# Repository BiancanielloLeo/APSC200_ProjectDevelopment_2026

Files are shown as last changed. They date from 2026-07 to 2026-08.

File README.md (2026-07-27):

##APSC200_ProjectDevelopment_2026

This repository contains the code and documentation for the SWEP 2026 project. Please refer to the documentation for all project details.

The "Software" folder contains all code to be ran on the users computer, the "Firmware" folder contains all the code to be ran on the robots, and the "Hardware" folder contains all the CAD models for the robots.

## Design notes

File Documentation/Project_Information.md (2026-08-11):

APSC 200 Project Development Multi-Agent Differential Drive Robotic System

Project Information

Leo Biancaniello Will Beveridge

Queen’s University Mathematics and Statistics Department

Summer 2026

## Contents

System Overview ................................................................................................................................................ 3 1 Software ..................................................................................................................................................... 4 1.1 Tracker ............................................................................................................................................... 4

1.1.1 ArUco Markers ................................................................................................................................ 4 1.2 Server ................................................................................................................................................. 5 2 Firmware..................................................................................................................................................... 7 2.1 Connection......................................................................................................................................... 7 2.2 Motion Planner.................................................................................................................................... 7 2.3 Motor Control ..................................................................................................................................... 8 2.3.1 Motors ............................................................................................................................................ 8 2.3.2 Encoders ........................................................................................................................................ 8 2.3.3 Pulse Counter ................................................................................................................................. 9 2.3.4 Control Law .................................................................................................................................... 9 2.3.5 Spot Turning Control ..................................................................................................................... 11 2.4 Battery Management ......................................................................................................................... 12 3 Hardware .................................................................................................................................................. 13 3.1 Chassis ............................................................................................................................................ 13 3.1.1 3d Print Settings ............................................................................................................................ 13 3.2 Assembly.......................................................................................................................................... 13 Appendix A: Electronics .................................................................................................................................... 15 A.1 Component Information .......................................................................................................................... 15 A.2 Pin Assignments...................................................................................................................................... 17 A.3 Pin Information ....................................................................................................................................... 18 Appendix B: Testing .......................................................................................................................................... 19 B.1 Feedforward ........................................................................................................................................... 19 B.2 Proportional and Integral ......................................................................................................................... 20 B.3 Turning ................................................................................................................................................... 20 Appendix C: Upgrades ...................................................................................................................................... 20

# System Overview

S

The robots operate on a consistent smooth tile floor

Path following (Free) vs Trajectory Generation (Timed) High and Low level control: Pure Pursuit,

Our goals are Position and Heading, but conventional control is in Linear and Angular Velocity

Collision avoidance should be on the robot itself. If it leaves the frame the server should keep running for the other robots, the one that no longer sees itself in the packets should just stop

# 1 Software

Software constitutes everything ran by the laptop. The system will use a distributed approach where the laptop is responsible for locating the position and heading of each robot, which it then communicates to all the robots that take the information and compute their new headings locally.

“initiation.py” (Should show what the UDP server is sending in the console) (On screen should be (ID, X, Y, Pose) (Simplify start up: List all robot ID’s being used then send 0 when you are done)

“tracker.py”

“udp.py”

Decouple the GUI from the tracking loop so that packets are sent as fast as possible and so that computation for the GUI doesn’t delay the tracker

## 1.1 Tracker

ALogitech C922 Pro Stream Webcam that runs at 30 fps with a 1920x1080p resolution is used to detect theArUco markers on the robots using OpenCV’s computer vision algorithm.

The camera is mounted overhead so there is no lens distortion or optical illusion, thus no anti-warping calibration is needed for the camera. The camera just needs its focus to be set using findFocus.py. The current best focus is a value of 15.

Since an external camera is being used, the camera source in the code needs to be changed from 0 to 1 if the laptop has a webcam*

The camera can view3600x2030mm of the floor so the algorithm should apply a cartesian plane to the center of the screen and convert the robot’s pixel positions to millimetres.

The robot’s positions are averaged from the detection of their four corners and the robot’s headings are taken as the angle between two of their corners in radians and are normalized to [−𝜋, 𝜋] where0° is facing right

DISPLAY FRAME RATE ON CAMERA FEED

## 1.1.1 ArUco Markers

The markers for the robots are a series of pixels that encode a binary number using black and white cells. The marker patterns are unique under rotation so that the pose of the robot can be determined from its marker orientation.

The algorithm detects the markers by looking for the black to white transition on it’s borders so it is important to always have a white border around the markers. The current markers are 95x95mm with a

## 2.5mmwhite border to make them 100x100mmwhich comes out to 375x375 pixels.

When detecting markers, the code returns the position of its four corners and the id of the marker. Then after detection the pose is estimated with the axes being shown (X-axis is Red, the Y-axis is Green, the Z- axis is Blue).

OpenCV has libraries on ArUco markers that provide dictionaries of different marker sizes and number of markers. It is better to use a shorter dictionary that only includes as many markers as you need as the inter-marker distance in the dictionary affects the cameras noise tolerance. We will use the 4x4_50 dictionary.

The markers are printed on matte 100lb cardstock that they do not bend as easily and have less glare

## 1.2 Server

AUDP (User Datagram Protocol) server will be used to broadcast the robots position data from the tracker to the robots. The UDP server will broadcast all robot positions in one packet to the address

## 255.255.255.255 on port 5005 on the router at a rate of 20 Hzto match the20 Hz robot heading logic

BROADCAST_IP = "255.255.255.255"

Since the UDP broadcast goes to every device n the network simultaneously, all robots receive the same packet at the same time.

Packets will be in the form:

- Byte 0 is the Packet Type (uint8) (RUN or STOP)
- Byte 1-4 are Sequence Numbers (uint32)
- Byte 5 is the Number of robots N (uint8)
- Bytes 6+ are the robot records

o 1 byte for Robot ID (uint8) o 2 bytes for X position (int16) - millimeters o 2 bytes for Y position (int16) - millimeters o 2 bytes for Heading (uint16) - radians x 1000 (scaled for int16 transmission)

Big-Endian format should be used so that byte order is unambiguous between the laptop and ESP, and information should be transmitted in millimetresandradians.

The server should have a response if a robot that is said to be active is not seen onscreen. This could be broadcasting a specific position (-9999, -9999) to indicate that the robot was lost or it could have a different response to tell the robot to stop.

WHEN THE ROBOT GOES OUT OF FRAME, THE SERVER JUST REPEATEDLY BROADCASTS IT’S LAST POSITION

There should be a start button. So when the server initializes, it should be in the stopped state, then you manually start it up

Binding SERVER_IP = "" doesn't affect the port. The bind tuple (IP, PORT) has two independent parts: the IP picks which interface on your laptop the socket attaches to, and the port is what your robots actually key on. Your server broadcasts to port 5005, so any robot listening on port 5005 receives the packet — no matter what your laptop's bind IP is. The robots never see your bind IP; they just watch for traffic on the agreed port. So the only thing that must match is the port: server sends to 5005, robots listen on 5005. Use SERVER_IP = "", keep SERVER_PORT = 5005, and you're set.

WHAT IS THE CAMERA LATENCY?

Test packets getting received

# 2 Firmware

Use New API v3.0+, ledcAttach(pin, freq, res) & ledcWrite(pin, duty) & ledcDetach(pin) With 20 kHz frequency and 8-bit resolution

The code that runs on the robots decodes the data from the server, determines the robots next headings, then controls the motors to move the robot. Serial communication should be at a Baud Rate of 115200 BATTERY MONITORING IS JITTERY AND THE VALUES NEED TO BE SMOOTHED

## 2.1 Connection

The robots have a built in WiFi module that will be used to read the port on the server to get the robots positions. Upon startup, the robots onboard LED should be RED when they are not connected to WiFi. Then once they connect to the specified network they should turn BLUE. Then when the robots are able to read the packets from the port they should turn GREEN. The robots should connect to “AgentWifi” with password “12345678” and port 5005 (ALL IT NEEDS IS THE THREE PIECES OF INFO) There should be a watch dog timer on the robots so that if they do not receive a packet for 1000msthey stop to avoid driving off screen.

Always use the newest packet in the sequence and discard old ones

## 2.2 Motion Planner

This should run at 20 Hz. The robot doesn’t need to make changes every loop, but it should compute everything to be able to make a decision The algorithm needs to compute what motor speeds are needed to get the robot to it’s next position using the formulas:

(𝑣 −𝐿⁄ × 𝜔)

2 𝑅𝑃𝑀𝐿 =× 60 2𝜋𝑟 (𝑣 +𝐿⁄ × 𝜔) 2 𝑅𝑃𝑀𝑅 =× 60 2𝜋𝑟

𝑣 is the desired velocity 𝜔 is the desired angular velocity 𝑟 is the radius of the wheel which is 32.5mm 𝐿 is the wheelbase between the two wheels which is 125mm

## 2.3 Motor Control

Two motors will spin at different speeds with the same power due to manufacturing tolerances. For the robots to drive straight and turn accurately, we need to control the motor speeds so that the wheels spin at the desired RPM (60-80 rpm). Thus, we will use feedforwardplusproportionaland integral control. We will run two separate control loops for each motor at 100 Hz.

NEED TO TEST MIN PWM FOR STRAIGHT AND TURNING Without battery voltage reference, the minimum duty to spin seems to be 70-75

## 2.3.1 Motors

The motors used are rated for a 6V input with a speed of 120 rpm at 0.20 kgcm of torque − IN1 and IN2 control direction. Having IN1 HIGH and IN2 LOW means forward, while the reverse means backwards. Both LOW means coast, and both HIGH means brake − STBY enables the motor driver so it must be HIGH to operate − PWM expects a pulse-width modulated square wave where the duty cycle controls the average motor voltage The PWM channel is configured at 20,000 Hz with 8-bit resolution so it runs a frequency of 20,000 Hz where the Duty Cycle can be set from 0 to 255 where 0 is 0% and 255 is 100%

## 2.3.2 Encoders

The encoders are Magnetic Wheel encoders with two hall effect sensors that output in quadrature (A/B channels). The encoders have A and B channels that generate square waves and are shifted so that the leading wave can indicate the direction of the motor spin. Channel A leading channel B means the motor is spinning CCW.

The state of the motor is determined by comparing the current encoder state with the previous encoder state and using a lookup table to determine if there is +1, -1, or 0 ticks.

The formula for the number of ticks per revolution is 7 × 𝐺𝑒𝑎𝑟 𝑅𝑎𝑡𝑖𝑜 × 𝑁𝑢𝑚𝑏𝑒𝑟 𝑜𝑓 𝐸𝑑𝑔𝑒𝑠. So, counting only the rising edge of one channel will give 350 ticks, while counting the change gives 700 ticks, and counting the change on both channels gives 1400 ticks which we will use.

## 2.3.3 Pulse Counter

Every time the encoders signal has a rising or falling edge, the CPU needs to take an interrupt to decode the signal. The ESP’s hardware PCNT (Pulse Counter) peripheral can count encoder pulses directly I hardware, so all the CPU needs to do is read the counter register when it’s needed.

The ESP32-S3-DEVKITC-1 has 4 hardware PCNT units (PCNT_UNIT_0 to PCNT_UNIT_3). Unit 0 will be used for the Left motor and Unit 1 will be used for the Right motor. In each unit are two other channels which will be used to read the two channels of each encoder.

Channel 0 is for Encoder Channel A and Channel 1 is for Encoder Channel B with their logic flipped in order to follow proper sequencing such that 00 -> 01 -> 11 -> 10… is Forward and 00 -> 10 -> 11 -> 01 is Backwards.

The ticks are stored in a 16-bit integer that wraps at ±32767. The program needs to use the current and last reading of ticks as that difference will be how much the wheel spun between intervals. The 16-bit integer arithmetic wraps will be automatically handled by the delta math. Just make sure that currentTicks and deltaTicks are both int16_t so that they wrap around the same.

In the function there is an invertDirection clause to make it so that the readings are dependent on if the robot is moving forwards or backwards, so the left unit is inverted and the right unit is normal.

The PCNT can accumulate ticks before the first loop which will through off the delta. Initially reset the accumulation or do something to prevent this issue.

## 2.3.4 Control Law

In this system, we view the input as the desired RPM from the motor, the control input being the PWM duty that we send, and the output being the actual speed of the motor which we read from the encoder.

Since we know somewhat about the dynamics of the motors, we will measure the PWM duty required to reach different RPM of the motor and then use those values for Feed forward control and then additionally use Proportionaland Integral control to get to our desired output.

The manage the Integral control, there is an anti-wind up clause and clamping so that the PWM duty never exceeds the safe rating of ~70%

NEEDS TO HANDLE SPINNING IN EITHER DIRECTION

The feedforward model duty = Kv·RPM + Ks is only valid for forward motion. The Ks term represents the static friction offset — the extra duty needed to overcome stiction and start moving. Because friction always opposes motion, this offset must always push in the direction of travel. For a negative (reverse) RPM command, the sign of the Ks term must follow the command direction:

- Forward (RPM > 0): duty = Kv·RPM + Ks
- Reverse (RPM < 0): duty = Kv·RPM − Ks

Generalized: duty = Kv·RPM + sign(RPM)·Ks If Ks is left positive for a reverse command, the offset partially cancels the command near zero RPM, making the motor sluggish to break free or unresponsive at low reverse speeds. Note that "inverting Ks" means flipping the sign of the term to match direction — Ks itself remains a positive constant. Companion changes required for reverse to work:

## 1. Signed feedforward output — compute the duty magnitude from |RPM|, then apply the

command's sign to the result.

## 2. Direction-aware motor drive — the motor function must set the H-bridge direction pins

from the sign of the duty, and write the magnitude to the PWM.

## 3. Symmetric saturation — the PI output and saturation limits must span [−MAX_DUTY,

+MAX_DUTY] instead of [0, MAX_DUTY], checking both rails.

## 4. Encoder measurement — already handles sign correctly (PCNT counts down for reverse),

so no change needed; the error term works in both directions. Accuracy note: Forward and reverse Ks are often not equal, due to direction-dependent gearbox and brush friction. For best accuracy, characterize each direction separately to obtain Ks_forward and Ks_reverse. Asymmetric Ks is the likely cause if the robot tracks straight forward but veers in reverse.

Thus the control law is

𝑃𝑊𝑀 𝑑𝑢𝑡𝑦 = (𝐾𝑣 × 𝑅𝑃𝑀𝑑𝑒𝑠𝑖𝑟𝑒𝑑 + 𝐾𝑠 × 𝑠𝑖𝑔𝑛(𝑅𝑃𝑀)) + (𝐾𝑃 × 𝐸𝑟𝑟𝑜𝑟 + 𝐾𝐼 × ∫ 𝐸𝑟𝑟𝑜𝑟)

Where Kv is the duty per RPM and Ks is the minimum PWM needed to overcome static friction which are determined through testing. It seems that 𝐾𝑣 should be around 1 and 𝐾𝑠 should be around 46.

A good starting point for 𝐾𝑃 is 2.5, and for 𝐾𝐼 is 1

Acceleration

Startup Acceleration Logic (Slew-Rate Limiting)

Problem. The largest source of heading error is the initial startup. When both motors are commanded from zero to a target RPM instantaneously, they do not break free at the same moment — small differences in static friction (Ks) and gearbox drag mean one wheel starts turning a few milliseconds before the other. During that brief window the robot pivots slightly. Because heading error is the integral of the speed difference between the wheels, any error that occurs before the PI loop catches up is permanent — the loop matches wheelspeeds thereafter but never undoes the initial pivot. Solution. Rather than commanding the target RPM instantly, ramp it up gradually from zero using a slew-rate limit.

This keeps both motors in the low-speed region longer, where the PI loop is actively correcting, so the instantaneous speed difference stays small throughout startup. A small difference over a gentle ramp produces far less heading error than a large difference over a sharp transient. It also reduces wheel slip and current spikes. Implementation. The control law itself is unchanged. A "current target" is maintained that chases the "commanded target" at a bounded rate each control tick: maxDelta = MAX_ACCEL_RPM_PER_SEC × dt rampedTarget moves toward commandedTarget by at most maxDelta per tick The ramped target (not the raw command) is then fed into the feedforward and error calculations. Key requirements:

- Shared ramp profile. Both wheels must ramp from a common profile and reach their targets

simultaneously. For straight driving, both use the same rate and target. For arcing (unequal wheel speeds), the wheels must ramp proportionally — scaling each wheel's rate so the ratio between them stays constant and both arrive together — otherwise the faster-arriving wheel briefly curves the path.

- Rate tuning. Start around 300–500 RPM/s and tune on the floor using the Serial Plotter. The two

actual-RPM traces should rise together and overlap during the ramp. Choose the fastest rate that still gives clean, matched startup; slower reduces heading error but launches sluggishly. Assessment. Worth implementing where heading accuracy matters, since it directly targets the identified startup failure mode. It is a small, low-risk addition — a few lines feeding a ramped target into the existing loop, with no change to characterization or the control law — at the cost of a slightly slower launch, which is an acceptable trade for straight-line heading.

## 2.3.5 Spot Turning Control

To turn on the spot, find the lowest DUTY that the robot needs to spin and then make a proportional plus minimum controller where the robot spins and get’s it’s heading from the server until it is at the desired angle.

The robot should try to turn in an open loop fashion where it only relies on the encoder ticks and then when it thinks it is in the right spot, it reads the next packet to check it’s position and adjust

BRAKE instead of COAST when at desired angle

arc_per_wheel = (|degrees| / 360) × π × wheel_track

ticks = arc_per_wheel / wheel_circumference × ticks_per_rev

Cap Spinning at 120 DUTY NEED MINIMUM TURNING DUTY + WHEELBASE CALIBRATION

## 2.4 Battery Management

𝑉𝑚𝑜𝑡𝑜𝑟 = 𝐷𝑢𝑡𝑦 × 𝑉𝑏𝑎𝑡𝑡𝑒𝑟𝑦

𝑃𝑊𝑀 𝑐𝑜𝑚𝑚𝑎𝑛𝑑 𝐷𝑢𝑡𝑦 =

255 Cap Vmotor at 6V so we aren’t running too much voltage to the motors The PWM duty cycle is between 0 and 1, but registered from 0-255

𝑉𝑛𝑜𝑚𝑖𝑛𝑎𝑙 𝑃𝑊𝑀𝑜𝑢𝑡 = 𝑃𝑊𝑀𝑐𝑜𝑚𝑚𝑎𝑛𝑑 × 𝑉𝑏𝑎𝑡𝑡𝑒𝑟𝑦 Example

## 7.2

𝑃𝑊𝑀𝑜𝑢𝑡 = 128 ×= 109.7

## 8.4

The battery readings are smoothed out with filtering. Moving average ring buffer with 16 samples only. It should update the battery voltage value at a frequency of 5 Hz

Voltage Divider 100 Kohm and 47 Kohm Batteries 7.2V nominal, 8.4V fully charged, 6.0V is the lowest it can safely drop Check everything with a multimeter

# 3 Hardware

The components will be assembled on two breadboards with a power rail in-between and be housed in a 3d printed chassis.

## 3.1 Chassis

The robot’s chassis are 100x100x90mm with2.5mm thick walls so that the interior is 95x95x90mm. The wheels are placed on the centerline of the chassis so that it can turn in place, and skid pads are added to the front and back to aid in balancing.

## 3.1.1 3d Print Settings

## 1.75mm PETG will be used with a 15% infill and 0.2mm layer height

## 3.2 Assembly

The assembly of the robots is very important and it should be done properly so that there are not any hardware issues in the future. First you must solder extensions onto the battery pack so that the Ground and Power wires are both 20cm. Then you must solder the Power wire to the switch and make the output wire 10cm. Then you need to extend all of the motor wires with Male DuPont cables so that they can be stuck into the breadboard. Motor wires should be cut at 9cmand have1. 5cm stripped for splicing. Then some 22 AWGwire should be cut to 12cmand have0. 5cm stripped for splicing. They should be connected with a V-Shape Twist Splice.

When assembling the breadboard circuits,22 AWG wires should be used and there should be 5mm of exposed wire on each end to snuggly fit into the holes. DON’T PUSH ON THE BACK OF THE ENCODER WHEN PUTTING IN MOTORS, IT WILL BEND THE MOTOR SHAFT AND BREAK THE MOTOR

The motors are press fit with their wires going towards the front of the chassis and being routed up through the cable holes. The Battery Pack goes in wire side first and has it’s wires pulled into the cable holder on the left side of the chassis. The switch should have the smooth side down and be secured with a zip tie.

Figure 1: Electronics Schematic

# Appendix A: Electronics

The robot uses an ESP32-S3-DEVKITC-1 v1.1 microcontroller that runs at 3.3V logic and has built-in WiFi. The motors have built in encoders and are controlled by a TB6612FNG motor driver. The robot will be powered by six AA batteries with a nominal voltage of 7.2V, going as high as 8.4V when fully charged.

The microcontroller uses Micro-USB and has a USB Port and a USB-to-UART Port. The USB-to-UART port is used for programming and serial monitoring. When programming, the ESP has automatic bootloader entry so the BOOT and RESET buttons do not need to be pressed, but they should be made accessible for troubleshooting.

The motor driver can accept 4.5V to 13.5V, but the motors are only rated for 6V, so the motor driver must be instructed to limit the PWM output to less than 70% to prevent the 7.2V of the battery from damaging the motors.

A voltage divider circuit is connected from the battery to an analog pin on the microcontroller so that the battery voltage can be monitored.

There is a capacitor at the battery terminals and at the microcontrollers terminals to smooth out current flow when components spontaneously demand high currents.

## A.1 Component Information

Microcontroller Development Board: − $23. 10 CAD -ESP32-S3-DEVKITC-1-N8R8 v1. 1, Adafruit 5336, Datasheet − 32-bit Dual Core Xtensa LX7 240MHz, 8MB PSRAM, 8MB Flash, Wi-Fi 4 − Can be programmed with exposed BOOT and RESET buttons − 45 GPIOs (0-21 and 26-48), 4x SPI, 3x UART, 2x I2C, all PWM capable except Powers, Grounds, and Resets − Has an onboard RGB LED − Has peak Wi-Fi draws of ~350mA Motor Driver: − $10. 04 CAD -TB6612FNG DC Motor Driver, Adafruit 2448, Datasheet − 2. 7V – 5V Logic and 4. 5V – 13. 5V Motor Supply − 1. 2A current per channel with 3.

2A peak − Supports PWM speed control, braking, and direction control − Internal Flyback, Thermal Shutdown, and Reverse Polarity Protections − ~90% Efficiency Motor with built in Encoder: − $18. 06 CAD -N20 DC Motor with Magnetic Encoder 1:50, Adafruit 4638, Datasheet − 6V DC 0. 2W with 100 mA running current and a ~200mA stall current (Can accept 4. 5V)

− 200 RPM No Load speed and 120 RPM Rated speed − 0. 20 Kgcm Rated torque and 0. 32 Kgcm Stall torque − 3-5V VCC for the Magnetic Quadrature Encoder with Dual Hall-Effect Sensors − Encoder output voltage is equal to the encoder supply voltage − PWM must be limited at 70% to semi-match battery voltage to input voltage* Wheels: − $3. 00 CAD -65mm Wheel for N20 Motor, Adafruit 4205, Datasheet − Hub is specifically designed to match the N20 D-Shaft Voltage Regulator: − $10. 84 CAD -AP63203 3. 3V Buck Regulator, SparkFun COM-18356, Datasheet − 3.

8V – 32V Input − 2A Max continuous output − ~88% Efficiency − Overcurrent, Thermal Shutdown, Undervoltage, Short-Circuit, and Electromagnetic Interference Protection − Recommends additional external capacitors* Battery: − $21. 99 CAD -Performance AA Rechargeable Batteries (This is a pack of 12, we need 6)

− Rechargeable Ni-MH 1. 2V 2400mAh − 7. 2V Nominal and 8. 4V when fully charged − $4. 20 CAD -Battery Holder, Datasheet Voltage Divider: − R1 = 100KΩ + R2 = 47KΩ − Current drain of 61𝜇A − Pin voltage never exceeds 3. 3V Capacitors: − 100𝜇F Electrolytic Capacitor − Between battery positive and ground before the converter − Must be rated above max battery voltage (8. 4V) − Positive Leg on positive battery and Negative Leg on ground − 47𝜇F Ceramic Capacitor − Close to ESP power pins − One leg on 3. 3v ESP pin and other leg on GND ESP pin Rocker Switch: − $1.

08 CAD -Two Prong Rocker Switch, SparkFun COM-11138, Datasheet − Backup $4. 40 CAD -Two Pring Rocker Switch, Datasheet − Two modes: ON and OFF − Two pins (One for IN, one for OUT)

2x 400-Pin Breadboards: − $3.27 CAD -400 Pin Breadboard − Needs removable rails 4x 2 Colour LEDS − $_.__ CAD –

− 5mm Diameter

## A.2 Pin Assignments

Battery: − Positive terminal goes to VIN on the Voltage Regulator − Positive terminal goes to PWRIN on the Motor Driver − Negative terminal goes to GND on the Voltage Regulator Voltage Regulator: − GND is tied to GND on the ESP − 3. 3V is tied to 3. 3V on the ESP Left Motor with Encoder: − M1 (White) is tied to MOTORA2 on the Motor Driver (So AIN1 HIGH, AIN2 LOW is Forward) − M2 (Red) is tied to MOTORA1 on the Motor Driver − VCC (Black) is tied to 3.

3V on the ESP − GND (Blue) is tied to GND on the ESP − C1 (Green) is tied to GPIO1 on the ESP(Direction is handled in code) − C2 (Yellow) is tied to GPIO2 on the ESP Right Motor with Encoder: − M1 (White) is tied to MOTORB1 on the Motor Driver (So BIN1 High, BIN2 LOW is Forward) − M2 (Red) is tied to MOTORB2 on the Motor Driver − VCC (Black) is tied to 3.

3V on the ESP − GND (Blue) is tied to GND on the ESP − C1 (Green) is tied to GPIO21 on the ESP (Direction is handled in code) − C2 (Yellow) is tied to GPIO47 on the ESP Motor Driver: − VCC is tied to 3. 3V on the ESP − GND is tied to GND on the ESP − PWMA is tied to GPIO4 on the ESP − AIN2 is tied to GPIO5 on the ESP − AIN1 is tied to GPIO6 on the ESP − STBY is tied to GPIO7 on the ESP − BIN1 is tied to GPIO8 on the ESP

− BIN2 is tied to GPIO9 on the ESP − PWMB is tied to GPIO10 on the ESP

Voltage Divider: − Positive Terminal of the battery goes to a 100KΩ resistor then is tied to GPIO18 on the ESP − The line to GPIO18 has a junction that goes to a 47KΩ that is tied to the negative terminal of the battery

Capacitors: − 100𝜇F Electrolytic Capacitor: Long (Positive) leg on the positive wire and Short (Negative) leg on the negative wire from the battery pack − 47𝜇F Ceramic Capacitor: Put as close as possible to the 3.3V and GND pins on the ESP

## A.3 Pin Information

- Total Pins:

o GPIO0-21 and GPIO26-48

- Safe Pins:

o GPIO1-2, GPIO4-18, GPIO21, GPIO39-42, GPIO47, GPIO48

- Unsafe Pins:

o GPIO0, GPIO3, GPIO45, GPIO46 are Boot Strapping Pins o GPIO19-20 are USB-JTAG Pins o GPIO26-32 are Internal SPI Flash / PSRAM Pins o GPIO33-37 are Octal SPI Expansion Pins o GPIO38 is the Onboard RGB LED o GPIO43-44 are TX and RX Pins

Pins 11, 12, 13, 14 are good spots for LED’s

# Appendix B: Testing

S

## B.1 Feedforward

Characterization

Purpose. Determine the feedforward model duty = Kv·RPM + Ks for each motor, where Kv is the duty required per unit RPM and Ks is the static offset (the duty needed to overcome friction and begin moving). This model provides the baseline duty command; the PI loop corrects residual error. Method. Characterization is performed with the wheels off the ground (no load). No-load conditions give the lowest measurement variance and ensure both motors are measured under identical conditions, which matters because the goal is matching the two motors rather than hitting an absolute RPM. The load-dependent behavior on the floor is handled by the PI loop, not the feedforward.

The routine steps the PWM duty from a minimum to a maximum value, recording steady-state RPM at each step, then fits a line by least-squares regression to extract Kv and Ks. Measures taken to improve accuracy and consistency:

- Raised the duty floor (MIN_MOVE_DUTY = 55) to avoid the low-duty stiction region, where

erratic RPM readings distort the fitted offset.

- Breakaway rejection — data points below 5 RPM (motor failed to break free) are excluded from

the fit.

- Long, true-timed measurement windows — 1000 ms per point, timed with micros() rather

than assuming the delay duration, to minimize quantization noise.

- Averaging— 5 sub-samples averaged per duty point.
- Bidirectional sweep — duty is swept up and then down, and both directions are combined in

the fit, averaging out backlash and friction hysteresis.

- Finer duty steps (CHAR_DUTY_STEP = 10) for more data points and a more stable fit.
- Warm-up — motors are run before characterizing so cold-vs-warm gearbox drag does not bias

results.

- Fit quality (R²) is computed and reported for each motor, providing a direct measure of how well

the linear model fits and flagging noisy data. Results. After these changes, characterization became consistent and repeatable across runs. Representative fits: both motors converged to Kv ≈ 0.97 and Ks ≈ 31, with R² ≥ 0.997 on every fit. Run- to-run variation in Kv fell to roughly 1.5%, small enough that the PI loop absorbs the difference. This was a marked improvement over early runs, where Ks varied by as much as 10 duty counts between runs and the two motors disagreed by ~8%.

No Load Characterization

No Load PI

Loaded PI

Safe range is 30-120 RPM

## B.2 Proportional and Integral

s

## B.3 Turning

The value for the wheelbase is what will determine the turning dynamics

# Appendix C: Upgrades

S

- Possibly use separate batteries for motors and for logic to prevent sag
- Switch to Lithium Polymer batteries and include a charging circuit on the robot
- Use buck-boost converters for both the Microcontroller and Motor Driver, but add drain protection
- Could switch to better motors that have higher torque at the same speed, but may not be necessary
- Could switch to motors that don’t have exposed gears

•

- Implement UWB positioning
- Make the PWM Duty for motor control dependent on the battery level

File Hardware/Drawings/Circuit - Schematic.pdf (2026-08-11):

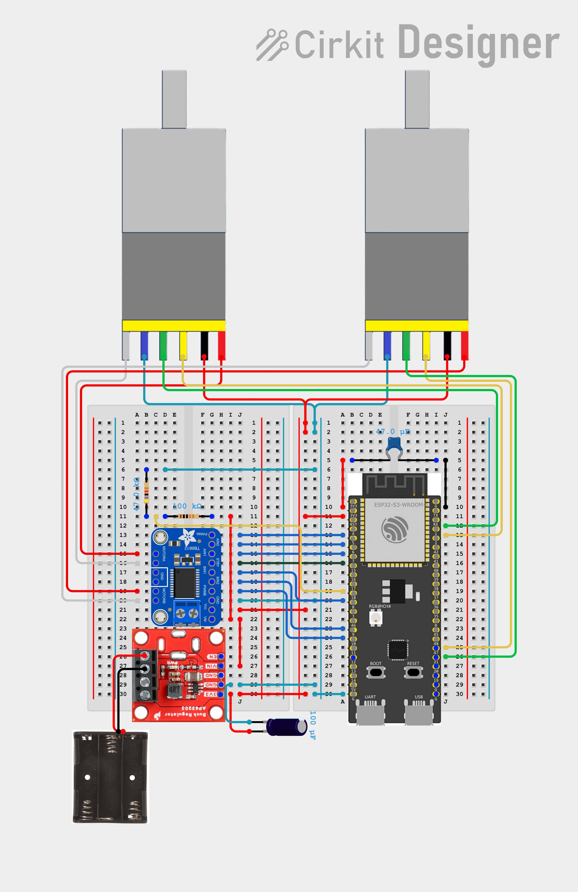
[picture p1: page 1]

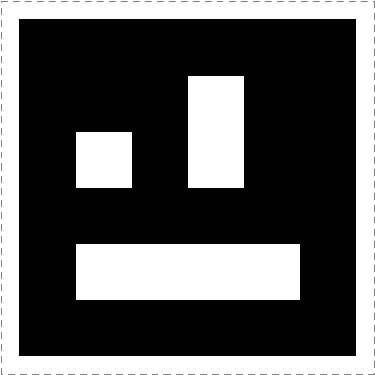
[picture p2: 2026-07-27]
Software/Computer Vision/4x4_50 ArUcos/aruco13.png

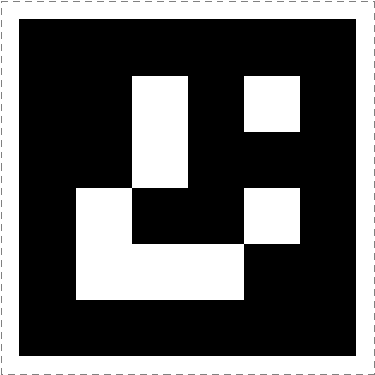
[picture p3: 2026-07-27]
Software/Computer Vision/4x4_50 ArUcos/aruco4.png

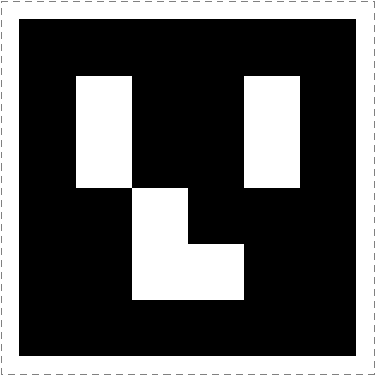
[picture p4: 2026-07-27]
Software/Computer Vision/4x4_50 ArUcos/aruco3.png

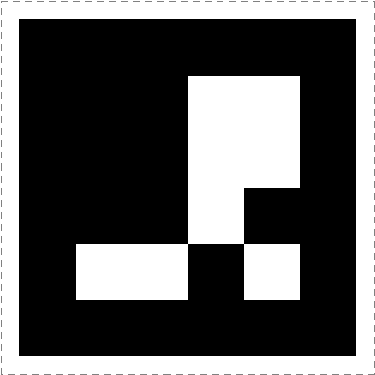
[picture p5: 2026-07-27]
Software/Computer Vision/4x4_50 ArUcos/aruco2.png

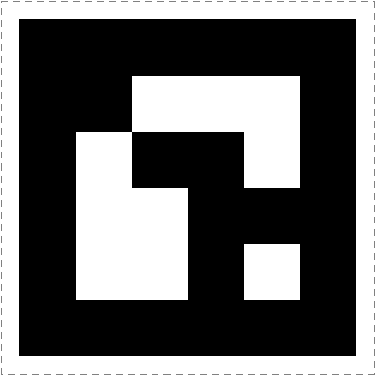
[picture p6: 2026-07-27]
Software/Computer Vision/4x4_50 ArUcos/aruco5.png

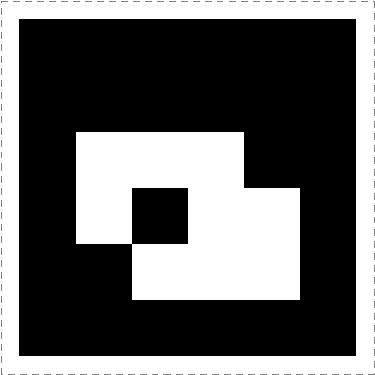
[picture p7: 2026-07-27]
Software/Computer Vision/4x4_50 ArUcos/aruco12.png

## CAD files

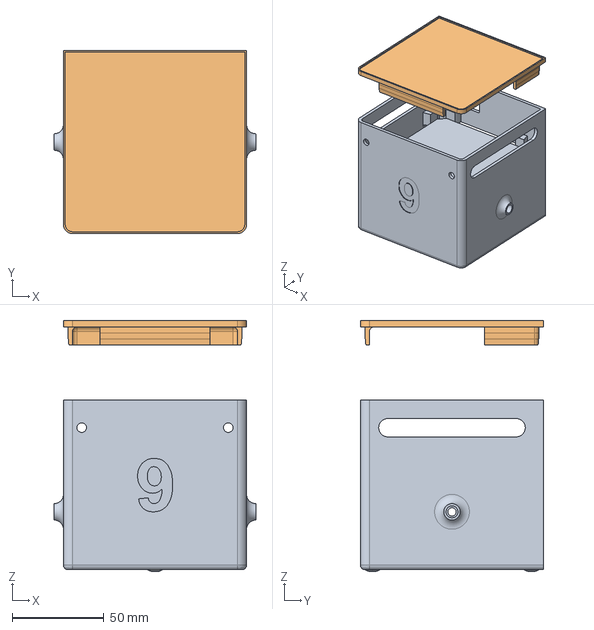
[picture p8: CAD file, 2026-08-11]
Hardware/Step Files/Chassis - 9.step
110.0 x 100.0 x 137.0 mm

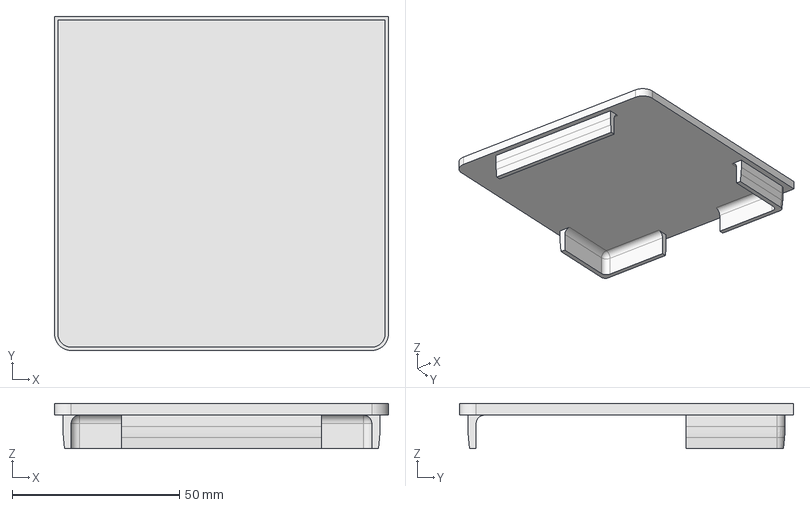
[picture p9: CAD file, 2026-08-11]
Hardware/Step Files/Roof - Blank.step
100.0 x 100.0 x 13.5 mm

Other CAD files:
Hardware/Step Files/Chassis - 8.step
Hardware/Step Files/Chassis - 7.step
Hardware/Step Files/Chassis - 2.step
Hardware/Step Files/Chassis - 1.step
Hardware/Step Files/Chassis - 4.step
Hardware/Step Files/Chassis - 6.step
Hardware/Step Files/Chassis - 11.step
Hardware/Step Files/Chassis - 3.step
Hardware/Step Files/Chassis - 12.step
Hardware/Step Files/Chassis - 5.step
Hardware/Step Files/Chassis - 10.step
Hardware/Step Files/Chassis - Blank.step
Hardware/Chassis - Blank.f3d

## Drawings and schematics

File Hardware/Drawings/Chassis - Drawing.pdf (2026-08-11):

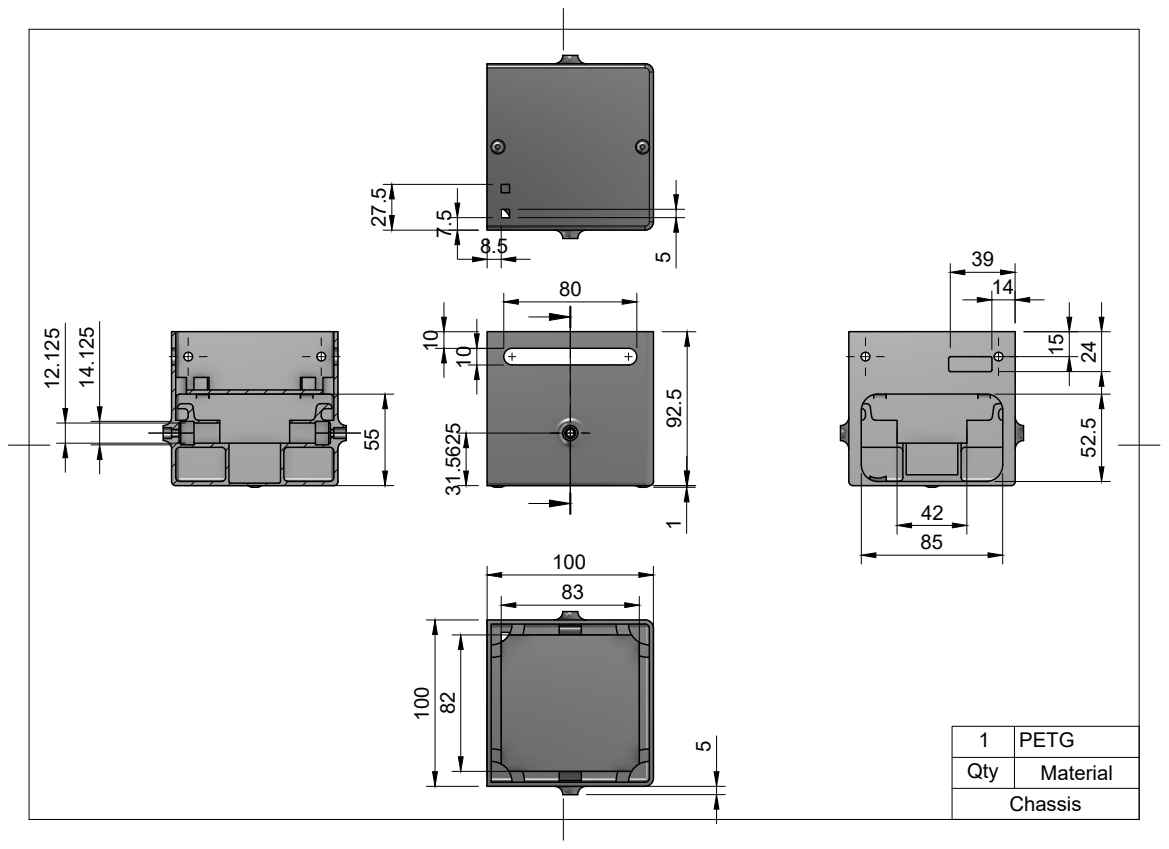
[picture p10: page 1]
Qty; Material 1; PETG 92.5 100

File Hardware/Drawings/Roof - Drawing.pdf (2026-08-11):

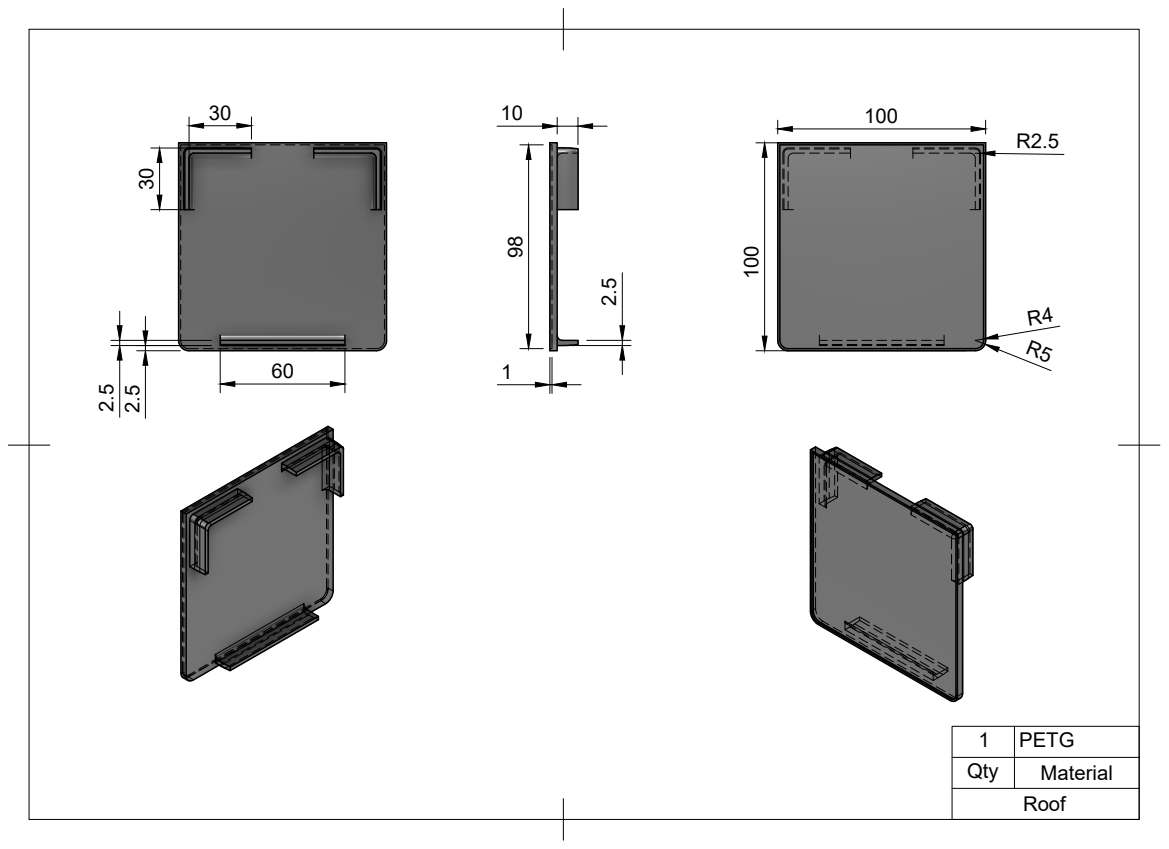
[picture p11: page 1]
Qty; Material 1; PETG

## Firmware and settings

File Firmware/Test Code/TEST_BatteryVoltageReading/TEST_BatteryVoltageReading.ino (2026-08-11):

// =============================================================================
// Simple Battery Monitor + Variable Motor Speed
// =============================================================================

#define BATTERY_PIN 18
#define PWMA_PIN    4
#define PWMB_PIN    10
#define AIN1_PIN    6
#define AIN2_PIN    5
#define BIN1_PIN    8
#define BIN2_PIN    9
#define STBY_PIN    7

// --- Voltage Divider ---
#define R1          100000.0f
#define R2           47000.0f
#define DIVIDER_RATIO (R2 / (R1 + R2))  // 0.3197
#define ADC_RESOLUTION 4095.0f
#define ADC_VREF    3.3f

// --- Moving Average Filter ---
#define MA_WINDOW 16
static float maBuffer[MA_WINDOW];
static int maIndex = 0;
static bool maFilled = false;

// --- PWM ---
#define PWM_FREQ 20000
#define PWM_RESOLUTION 8

// --- Runtime state ---
static int g_motorDuty = 0;
static bool g_motorsRunning = false;
static unsigned long g_startTime = 0;
static float g_startVoltage = 0.0f;

float batteryReadVoltage() {
    long sum = 0;
    for (int i = 0; i < 8; i++) {
        sum += analogRead(BATTERY_PIN);
    }
    float adcAvg = sum / 8.0f;
    float pinVolts = (adcAvg / ADC_RESOLUTION) * ADC_VREF;
    float battVolts = pinVolts / DIVIDER_RATIO;
    return battVolts;
}

float batteryGetFiltered() {
    float raw = batteryReadVoltage();
    
    // Add to moving average buffer
    maBuffer[maIndex] = raw;
    maIndex = (maIndex + 1) % MA_WINDOW;
    
    // Average the buffer
    float sum = 0;
    for (int i = 0; i < MA_WINDOW; i++) {
        sum += maBuffer[i];
    }
    return sum / MA_WINDOW;
}

// Scale duty based on battery voltage
// At 7.2V nominal: duty = requested
// At lower voltage: duty scales up to maintain torque
// At higher voltage: duty scales down to protect motor
int scaleDutyByBattery(int requestedDuty, float batteryVoltage) {
    float scaleFactor = 7.2f / batteryVoltage;  // Normalize to 7.2V
    int scaledDuty = (int)(requestedDuty * scaleFactor);
    
    // Cap at 255 to avoid overflow
    if (scaledDuty > 255) scaledDuty = 255;
    
    return scaledDuty;
}

void motorSetDuty(int dutyA, int dutyB, float batteryVoltage) {
    int scaledA = scaleDutyByBattery(dutyA, batteryVoltage);
    int scaledB = scaleDutyByBattery(dutyB, batteryVoltage);
    
    digitalWrite(STBY_PIN, HIGH);
    digitalWrite(AIN1_PIN, HIGH);
    digitalWrite(AIN2_PIN, LOW);
    digitalWrite(BIN1_PIN, HIGH);
    digitalWrite(BIN2_PIN, LOW);
    ledcWrite(PWMA_PIN, scaledA);
    ledcWrite(PWMB_PIN, scaledB);
}

void motorStop() {
    ledcWrite(PWMA_PIN, 0);
    ledcWrite(PWMB_PIN, 0);
    digitalWrite(STBY_PIN, LOW);
    g_motorsRunning = false;
}

void printMenu() {
    Serial.println("\n=== Battery Monitor + Motor Control ===");
    Serial.println("Commands:");
    Serial.println("  run <0-255> - Run motors at duty (watch battery drain)");
    Serial.println("  stop - Stop motors");
    Serial.println("  a <0-255> - Set motor A speed (one-time)");
    Serial.println("  b <0-255> - Set motor B speed (one-time)");
    Serial.println("  ab <0-255> - Set both motors (one-time)");
    Serial.println("  m - Show this menu");
    Serial.println("====================================\n");
}

void setup() {
    Serial.begin(115200);
    delay(1000);
    
    pinMode(BATTERY_PIN, INPUT);
    pinMode(AIN1_PIN, OUTPUT);
    pinMode(AIN2_PIN, OUTPUT);
    pinMode(BIN1_PIN, OUTPUT);
    pinMode(BIN2_PIN, OUTPUT);
    pinMode(STBY_PIN, OUTPUT);
    
    ledcAttach(PWMA_PIN, PWM_FREQ, PWM_RESOLUTION);
    ledcAttach(PWMB_PIN, PWM_FREQ, PWM_RESOLUTION);
    
    // Seed moving average
    for (int i = 0; i < MA_WINDOW; i++) {
        maBuffer[i] = batteryReadVoltage();
    }
    
    printMenu();
}

void loop() {
    float v = batteryGetFiltered();
    
    // Print battery every 1000ms
    static unsigned long lastPrint = 0;
    if (millis() - lastPrint >= 1000) {
        lastPrint = millis();
        float pct = (v - 6.0) / (8.4 - 6.0) * 100.0f;
        if (pct > 100) pct = 100;
        if (pct < 0) pct = 0;
        Serial.printf("Battery: %.2fV  (%.1f%%)\n", v, pct);
    }
    
    // Keep motors running if in continuous mode
    if (g_motorsRunning) {
        motorSetDuty(g_motorDuty, g_motorDuty, v);
    }
    
    // Parse serial commands
    if (Serial.available()) {
        String input = Serial.readStringUntil('\n');
        input.trim();
        
        // Split command and argument
        int spaceIndex = input.indexOf(' ');
        String cmd = (spaceIndex > 0) ? input.substring(0, spaceIndex) : input;
        
        if (cmd == "run") {
            int duty = input.substring(spaceIndex + 1).toInt();
            g_motorDuty = duty;
            g_motorsRunning = true;
            g_startTime = millis();
            g_startVoltage = v;
            int scaled = scaleDutyByBattery(duty, v);
            Serial.printf("Running motors at %d (scaled to %d)\n", duty, scaled);
        }
        else if (cmd == "stop") {
            motorStop();
            Serial.println("Motors stopped");
        }
        else if (cmd == "a") {
            int duty = input.substring(spaceIndex + 1).toInt();
            motorSetDuty(duty, 0, v);
            int scaled = scaleDutyByBattery(duty, v);
            Serial.printf("Motor A: %d (scaled to %d)\n", duty, scaled);
        }
        else if (cmd == "b") {
            int duty = input.substring(spaceIndex + 1).toInt();
            motorSetDuty(0, duty, v);
            int scaled = scaleDutyByBattery(duty, v);
            Serial.printf("Motor B: %d (scaled to %d)\n", duty, scaled);
        }
        else if (cmd == "ab") {
            int duty = input.substring(spaceIndex + 1).toInt();
            motorSetDuty(duty, duty, v);
            int scaled = scaleDutyByBattery(duty, v);
            Serial.printf("Both motors: %d (scaled to %d)\n", duty, scaled);
        }
        else if (cmd == "m") {
            printMenu();
        }
    }
}

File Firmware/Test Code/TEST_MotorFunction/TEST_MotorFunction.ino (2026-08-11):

//Leo Biancaniello + Claude

// ============================================================
// This code is intended to test the motors response to different inputs
// When the robot is assembled, run this test first to check the motors
//
// Connect the usb to your device and use the serial monitor to pick between different tests
// Watch the motors and check that the response is as expected
// ============================================================


// --- Pin Definitions ---
#define PWMA_PIN   4
#define AIN1_PIN   6
#define AIN2_PIN   5
#define STBY_PIN   7
#define BIN1_PIN   8
#define BIN2_PIN   9
#define PWMB_PIN   10

// --- PWM Config ---
#define PWM_FREQ       20000   // 20 kHz
#define PWM_RESOLUTION 8       // 8-bit (0–255)
#define MAX_DUTY       178     // 70% of 255 — motor voltage cap
#define TEST_DUTY      128     // 50% — used for on/coast/brake tests
#define RAMP_STEP_MS   15      // ms between ramp steps

// ============================================================
//  Setup
// ============================================================
void setup() {
  Serial.begin(115200);
  while (!Serial) delay(10);

  pinMode(AIN1_PIN, OUTPUT);
  pinMode(AIN2_PIN, OUTPUT);
  pinMode(BIN1_PIN, OUTPUT);
  pinMode(BIN2_PIN, OUTPUT);
  pinMode(STBY_PIN, OUTPUT);

  // LEDC pin-based API (ESP32 Arduino Core v3.0+)
  ledcAttach(PWMA_PIN, PWM_FREQ, PWM_RESOLUTION);
  ledcAttach(PWMB_PIN, PWM_FREQ, PWM_RESOLUTION);

  // Start safe
  allOff();

  printMenu();
}

// ============================================================
//  Main Loop — Serial Menu
// ============================================================
void loop() {
  if (Serial.available()) {
    char cmd = Serial.read();
    while (Serial.available()) Serial.read(); // flush newline

    switch (cmd) {
      case '1': testOnLeft();   break;
      case '2': testOnRight();  break;
      case '3': testOnBoth();   break;
      case '4': testRampLeft(); break;
      case '5': testRampRight();break;
      case '6': testRampBoth(); break;
      case '7': testCoast();    break;
      case '8': testBrake();    break;
      case '0': allOff();       Serial.println("All motors off.\n"); printMenu(); break;
      case 'm': printMenu();    break;
      default:
        Serial.println("Unknown command. Press 'm' to show the menu.\n");
        break;
    }
  }
}

// ============================================================
//  Menu
// ============================================================
void printMenu() {
  Serial.println("========================================");
  Serial.println("         MOTOR TEST MENU");
  Serial.println("  (Place robot on its side first!)");
  Serial.println("========================================");
  Serial.println(" 1 - Left motor on  (50%, forward)");
  Serial.println(" 2 - Right motor on (50%, forward)");
  Serial.println(" 3 - Both motors on (50%, forward)");
  Serial.println(" ------");
  Serial.println(" 4 - Ramp left motor  (0 → 70% → 0)");
  Serial.println(" 5 - Ramp right motor (0 → 70% → 0)");
  Serial.println(" 6 - Ramp both motors (0 → 70% → 0)");
  Serial.println(" ------");
  Serial.println(" 7 - Coast (runs both at 50%, then coasts)");
  Serial.println(" 8 - Brake (runs both at 50%, then brakes)");
  Serial.println(" ------");
  Serial.println(" 0 - All motors off");
  Serial.println(" m - Show this menu");
  Serial.println("========================================\n");
}

// ============================================================
//  Tests 1–3: Motor On
// ============================================================
void testOnLeft() {
  Serial.println("[1] Left motor ON at 50% forward.");
  enableDriver();
  setLeft(true);
  ledcWrite(PWMA_PIN, TEST_DUTY);
  ledcWrite(PWMB_PIN, 0);
  Serial.println("    Press '0' to stop.\n");
}

void testOnRight() {
  Serial.println("[2] Right motor ON at 50% forward.");
  enableDriver();
  setRight(true);
  ledcWrite(PWMA_PIN, 0);
  ledcWrite(PWMB_PIN, TEST_DUTY);
  Serial.println("    Press '0' to stop.\n");
}

void testOnBoth() {
  Serial.println("[3] Both motors ON at 50% forward.");
  enableDriver();
  setLeft(true);
  setRight(true);
  ledcWrite(PWMA_PIN, TEST_DUTY);
  ledcWrite(PWMB_PIN, TEST_DUTY);
  Serial.println("    Press '0' to stop.\n");
}

// ============================================================
//  Tests 4–6: Ramp
// ============================================================
void testRampLeft() {
  Serial.println("[4] Ramping LEFT motor: 0 → 70% → 0");
  enableDriver();
  setLeft(true);
  setRight(true);
  ledcWrite(PWMB_PIN, 0); // right stays off
  ramp(PWMA_PIN, 0, MAX_DUTY);
  delay(500);
  ramp(PWMA_PIN, MAX_DUTY, 0);
  allOff();
  Serial.println("    Done.\n");
  printMenu();
}

void testRampRight() {
  Serial.println("[5] Ramping RIGHT motor: 0 → 70% → 0");
  enableDriver();
  setLeft(true);
  setRight(true);
  ledcWrite(PWMA_PIN, 0); // left stays off
  ramp(PWMB_PIN, 0, MAX_DUTY);
  delay(500);
  ramp(PWMB_PIN, MAX_DUTY, 0);
  allOff();
  Serial.println("    Done.\n");
  printMenu();
}

void testRampBoth() {
  Serial.println("[6] Ramping BOTH motors: 0 → 70% → 0");
  enableDriver();
  setLeft(true);
  setRight(true);
  for (int duty = 0; duty <= MAX_DUTY; duty++) {
    ledcWrite(PWMA_PIN, duty);
    ledcWrite(PWMB_PIN, duty);
    printDuty(duty);
    delay(RAMP_STEP_MS);
  }
  delay(500);
  for (int duty = MAX_DUTY; duty >= 0; duty--) {
    ledcWrite(PWMA_PIN, duty);
    ledcWrite(PWMB_PIN, duty);
    printDuty(duty);
    delay(RAMP_STEP_MS);
  }
  allOff();
  Serial.println("    Done.\n");
  printMenu();
}

// ============================================================
//  Tests 7–8: Coast and Brake
// ============================================================
void testCoast() {
  Serial.println("[7] Both motors at 50% for 2s, then COAST.");
  enableDriver();
  setLeft(true);
  setRight(true);
  ledcWrite(PWMA_PIN, TEST_DUTY);
  ledcWrite(PWMB_PIN, TEST_DUTY);
  delay(2000);
  Serial.println("    Coasting — motors spin down freely...");
  digitalWrite(AIN1_PIN, LOW);
  digitalWrite(AIN2_PIN, LOW);
  digitalWrite(BIN1_PIN, LOW);
  digitalWrite(BIN2_PIN, LOW);
  ledcWrite(PWMA_PIN, 0);
  ledcWrite(PWMB_PIN, 0);
  Serial.println("    Press '0' when done observing.\n");
}

void testBrake() {
  Serial.println("[8] Both motors at 50% for 2s, then BRAKE.");
  enableDriver();
  setLeft(true);
  setRight(true);
  ledcWrite(PWMA_PIN, TEST_DUTY);
  ledcWrite(PWMB_PIN, TEST_DUTY);
  delay(2000);
  Serial.println("    Braking — motors stop hard...");
  digitalWrite(AIN1_PIN, HIGH);
  digitalWrite(AIN2_PIN, HIGH);
  digitalWrite(BIN1_PIN, HIGH);
  digitalWrite(BIN2_PIN, HIGH);
  ledcWrite(PWMA_PIN, 0);
  ledcWrite(PWMB_PIN, 0);
  Serial.println("    Press '0' when done observing.\n");
}

// ============================================================
//  Helpers
// ============================================================
void enableDriver() {
  digitalWrite(STBY_PIN, HIGH);
}
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

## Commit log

2026-07-27 Initial commit of project folders
    [Chassis - Blank.stp, Roof - Blank.stp]
2026-08-11 More Files
    [Chassis - 1.step, Chassis - 10.step, Chassis - 11.step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]
